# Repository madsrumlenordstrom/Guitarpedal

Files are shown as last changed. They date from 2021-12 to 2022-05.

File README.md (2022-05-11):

## An open source distortion pedal
The design is all analog and uses diodes to distort the input signal.
It has 3 different modes of distortion. It is possible to either use germanium, silicon or LED's in the hard clipping stage. It is also possible to just use soft clipping.
Schematic

The PCB is four layers since it so mouch nicer to work with and has become so cheap that two layer PCB are more or less obsolete. I wanted every component to be on the PCB and not having to deal with soldering extra wires to connectors and pots. So when every component is soldered to the PCB, the pedal is essentially done, and just needs to be put into an enclosure. Instead of having a enclosure with art on I designed the PCB to be aesthetically pleasing.
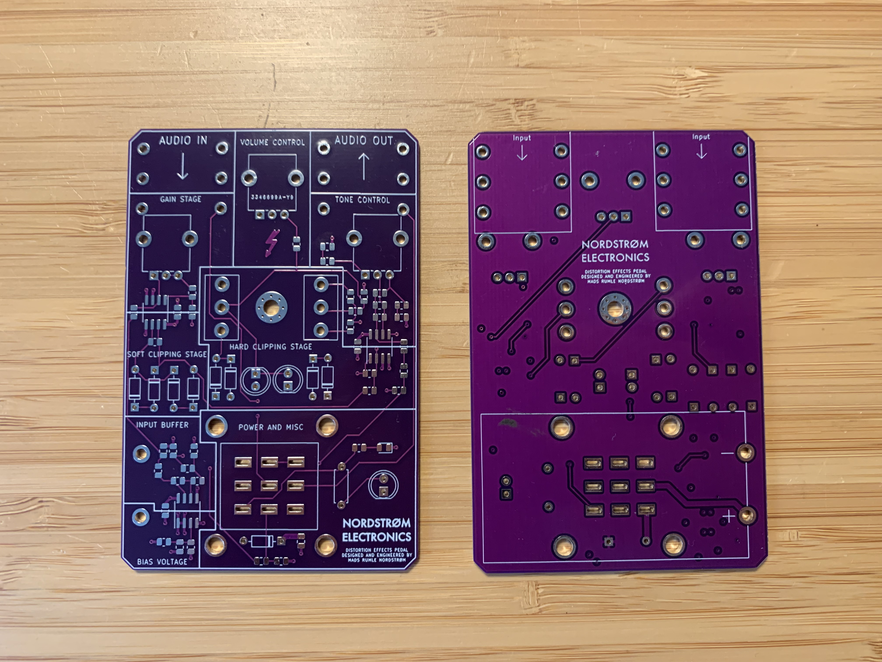
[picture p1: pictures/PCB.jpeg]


I using an acryllic plate as the lid on an aluminium enclosure, so the PCB is visible. As you can see on the pictures grease and dust becomes very visible on the acryllic lid. Acryllic is also a pain to work with as it is very brittle and can more or less only be cut out nicely on a CO2 laser. Next time I will probably find another material. However I do think the final product turned out nicely!
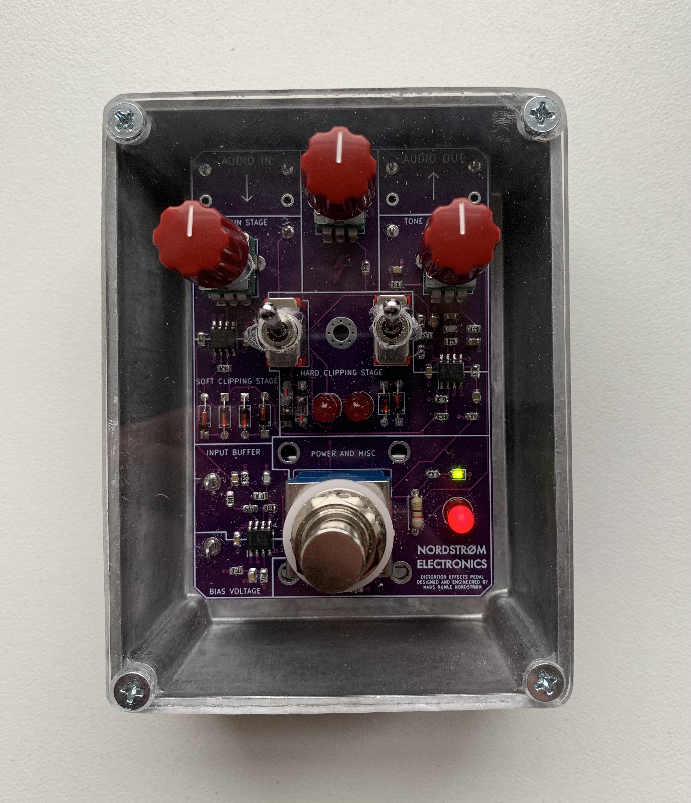
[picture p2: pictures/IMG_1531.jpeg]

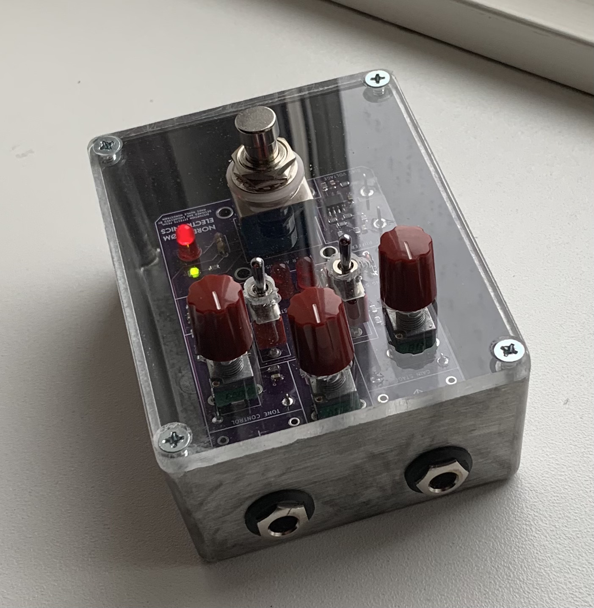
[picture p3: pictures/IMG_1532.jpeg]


More pictures can be found in the pictures folder.
Personally I don't play any intrusments. This projects was made as a gift for family and friends. People who have been gifted this pedal like and generally think it sounds good, so I am quite satisfied with the result.

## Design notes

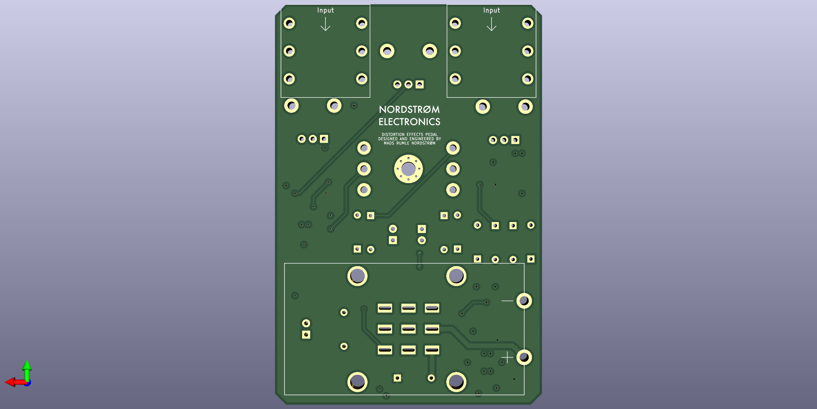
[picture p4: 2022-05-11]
pictures/PCB-render-back.png

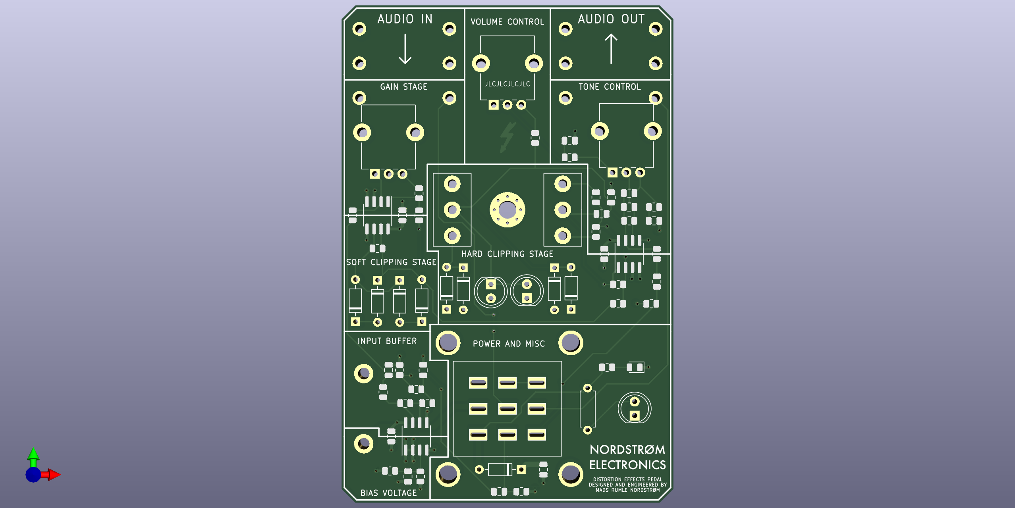
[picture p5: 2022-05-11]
pictures/PCB-render-front.png

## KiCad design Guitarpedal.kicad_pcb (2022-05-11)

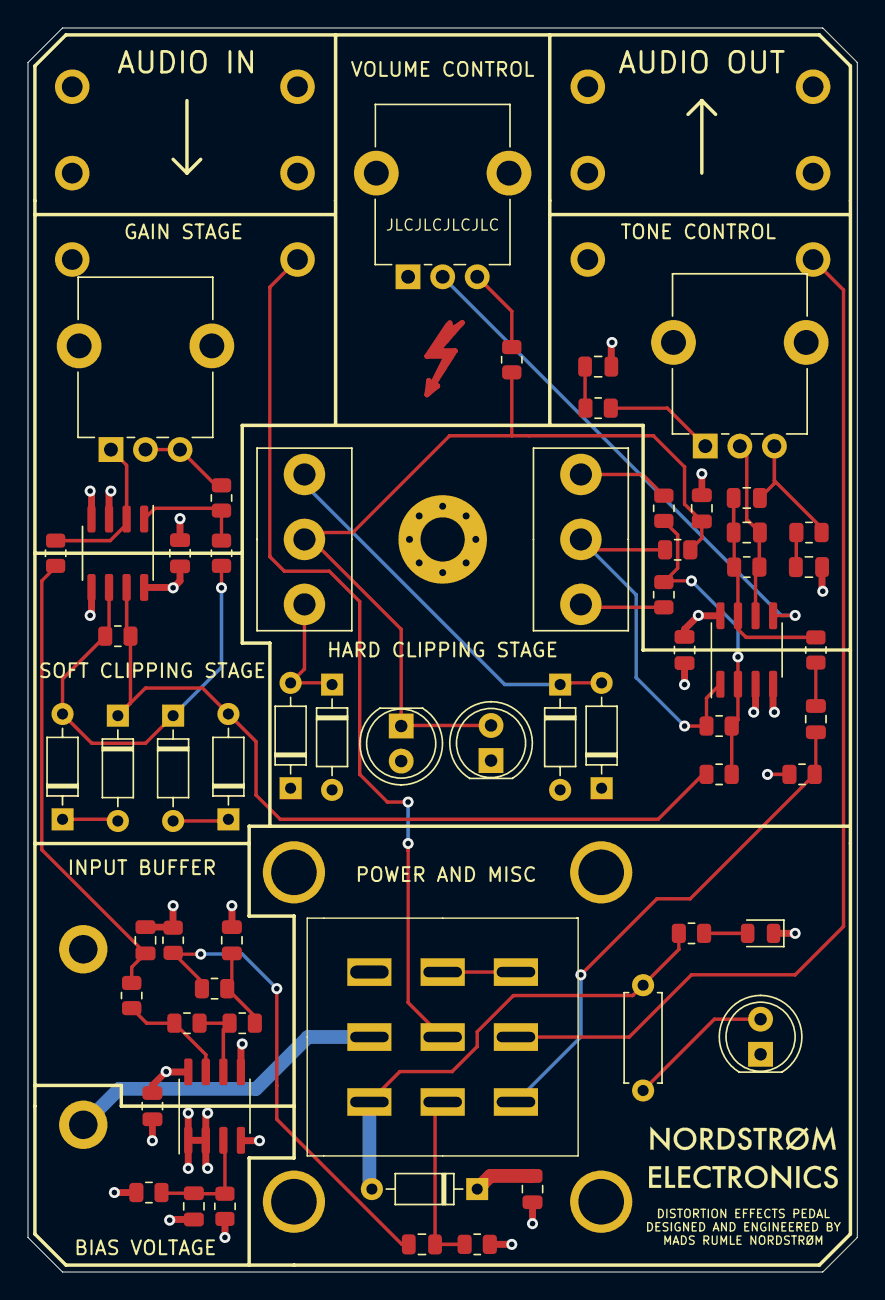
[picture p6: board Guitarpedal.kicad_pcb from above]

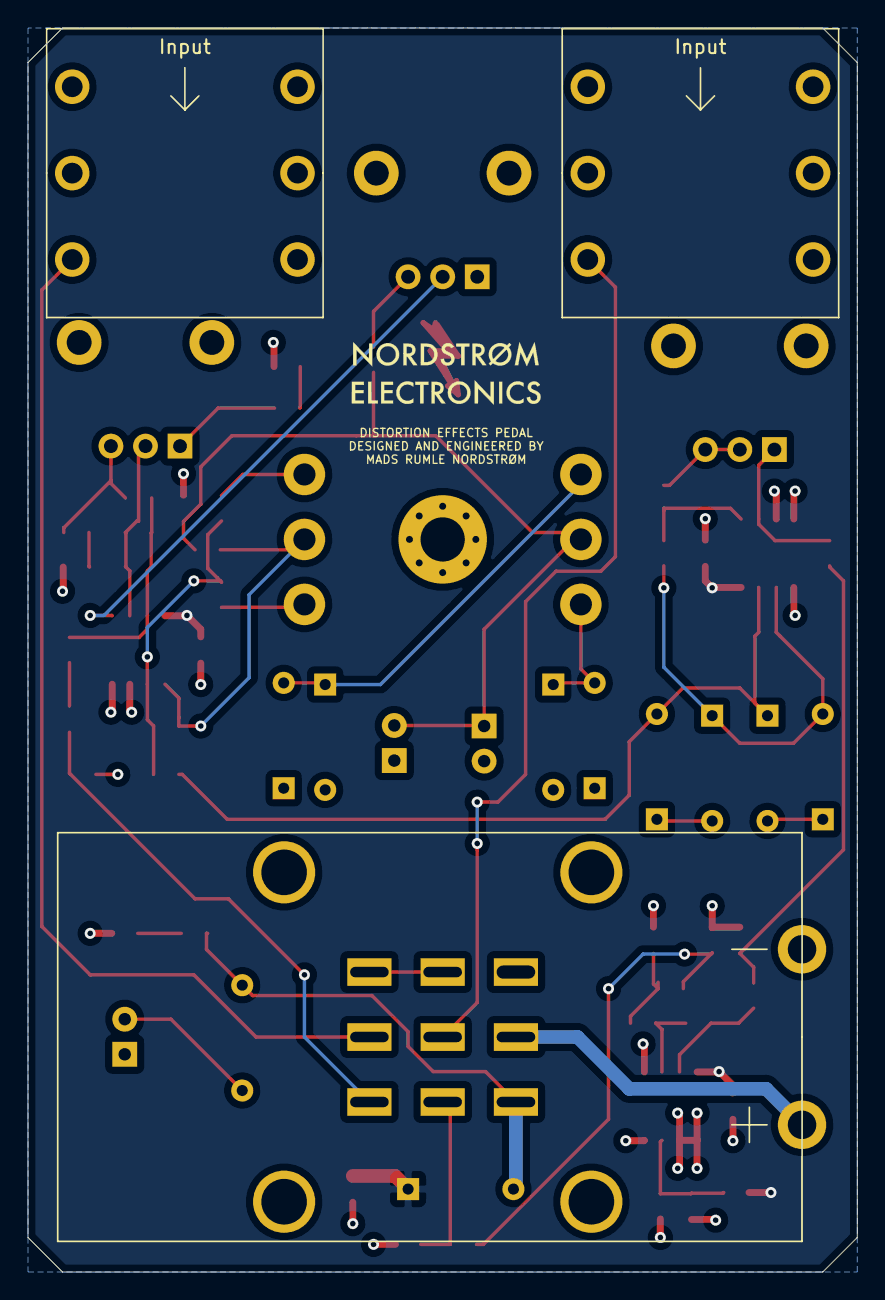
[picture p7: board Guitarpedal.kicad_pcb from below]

Board: 4 copper layers, 60.0 x 90.0 mm, 65 parts (3 on the bottom side), 41 nets.

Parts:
BT1: Battery_Cell; 9V_Battery_Holder_1294
C1, C11, C15: 10u; C_0805_2012Metric
C2, C3, C4, C6, C13, C14: 100n; C_0805_2012Metric
C7: 10n; C_0805_2012Metric
C8: 33n; C_0805_2012Metric
C9: 47p; C_0805_2012Metric
C10: 1n; C_0805_2012Metric
C12: 3.3n; C_0805_2012Metric
D1, D3, D4: D_Schottky; D_DO-35_SOD27_P7.62mm_Horizontal
D2: LED; LED_0805_2012Metric
D5, D6, D9, D10, D11, D12: 1N4148; D_DO-35_SOD27_P7.62mm_Horizontal
D7, D8, D13: LED; LED_D5.0mm
H1: MountingHole_Pad; MountingHole_3.2mm_M3_Pad_Via
J1, J2: AudioJack2; ACJM-IH
R1, R6: 649; R_0805_2012Metric
R2, R3: 102k; R_0805_2012Metric
R4: 26.7k; R_0805_2012Metric
R5: 16.9k; R_0805_2012Metric
R7, R8, R9: 10k; R_0805_2012Metric
R10, R16: 40.2k; R_0805_2012Metric
R11, R18: 931k; R_0805_2012Metric
R12: 499k; R_0805_2012Metric
R13: 80.6k; R_0805_2012Metric
R14: 24.9k; R_0805_2012Metric
R15: 4.99k; R_0805_2012Metric
R17: 1k; R_0805_2012Metric
R19: 17.4k; R_0805_2012Metric
R20: 56.2k; R_0805_2012Metric
R21: 6.81k; R_0805_2012Metric
R22: 3.24k; R_0805_2012Metric
R23: 22.1k; R_0805_2012Metric
R24: 1.2k; R_Axial_DIN0207_L6.3mm_D2.5mm_P7.62mm_Horizontal
R25: 105k; R_0805_2012Metric
RV1: 1M; Potentiometer_Alpha_RD901F-40-00D_Single_Vertical_CircularH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
RV2: 100k; Potentiometer_Alpha_RD901F-40-00D_Single_Vertical_CircularH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
RV3: 50k; Potentiometer_Alpha_RD901F-40-00D_Single_Vertical_CircularH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
SW1, SW2: SW_SPDT; 100SP1T1B4M2QE
U1, U2, U3: TL072; SOIC-8_3.9x4.9mm_P1.27mm
U4: 3PDT_footswitch; 3PDT

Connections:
4V5: C9.1, C10.1, D3.2, D4.1, D5.2, D6.1, D7.2, D8.1, R12.2, RV2.1, U1.1, U1.2, U1.5, U2.3, U2.5, U3.3
+9V: C1.2, C2.2, C3.2, C4.2, D1.1, R2.1, U1.8, U2.8, U3.8
Audio_in: C7.2, R11.1, U4.6
Buffer_out: C10.2, R9.2, R16.1
GND: BT1.2, C1.1, C2.1, C3.1, C4.1, C6.1, C8.1, C14.1, C15.1, D2.1, D13.1, H1.1, J1.S, J2.S, R3.2, R11.2, R18.2, U1.4, U2.4, U3.4
Gain_out: R15.2, R23.1, U2.1
Hard_clipping_out: C8.2, D7.1, D8.2, R6.2, R25.1, SW2.2
unnamed: BT1.1, U4.2
unnamed: C6.2, R2.2, R3.1, U1.3
unnamed: C7.1, R7.1, R12.1
unnamed: C9.2, R7.2, R8.1
unnamed: C11.2, R17.2
unnamed: C12.1, C13.2, R17.1, R19.2, U3.7
unnamed: C12.2, R19.1, RV3.2, U3.6
unnamed: C13.1, R22.1, RV3.3
unnamed: C14.2, R21.1
unnamed: C15.2, R22.2
unnamed: D2.2, R1.2
unnamed: D3.1, D4.2, SW2.1
unnamed: D5.1, D6.2, SW2.3
unnamed: D9.1, D10.2
unnamed: D9.2, D11.1, R20.1, R23.2, U2.6
unnamed: D11.2, D12.1
unnamed: D13.2, R24.2
unnamed: J1.T, U4.5
unnamed: J2.T, U4.8
unnamed: R4.1, R8.2, U1.6
unnamed: R4.2, R9.1, U1.7
unnamed: R5.2, SW1.3
unnamed: R5.1, R10.1, R13.1, R14.2, U3.2
unnamed: R10.2, SW1.1
unnamed: R6.1, R13.2, SW1.2, U3.1
unnamed: R15.1, RV1.2, RV1.3
unnamed: R16.2, RV1.1, U2.2
unnamed: R21.2, RV3.1
unnamed: R25.2, RV2.3
unnamed: RV2.2, U3.5
unnamed: U4.4, U4.7
Power_in: D1.2, R1.1, R24.1, U4.3
Soft_clipping_out: D10.1, D12.2, R14.1, R20.2, U2.7
Tone_control_out: C11.1, R18.1, U4.9

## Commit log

2021-12-23 First version
    [Guitarpedal-B_Cu.gbr, Guitarpedal-B_Mask.gbr, Guitarpedal-B_Paste.gbr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]
2022-05-11 Updated to 6.0
    [Guitarpedal.kicad_pcb, Guitarpedal.kicad_sch, Guitarpedal.sch]
2022-05-11 Added readme and pictures
    [Guitarpedal-B_Cu.gbr, Guitarpedal-B_Mask.gbr, Guitarpedal-B_Paste.gbr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]
